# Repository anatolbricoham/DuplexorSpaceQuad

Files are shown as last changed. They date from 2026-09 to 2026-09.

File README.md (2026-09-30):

# Diplexor 2 m / 70 cm: PCB y caja imprimible (SMA y BNC)

Diplexor pasivo que separa las bandas de **2 m (144–146 MHz)** y **70 cm (430–440 MHz)** de un único conector de radio. Hay dos versiones que solo se diferencian en los conectores (**SMA** o **BNC**). Cada una tiene su PCB de 2 capas y su caja para impresora 3D, diseñada lo más compacta posible.

| | SMA | BNC |
|---|---|---|
| PCB | 37 × 23 mm | 55.5 × 33 mm |
| Caja (exterior) | **45.2 × 27.6 × 14.1 mm** | **59.9 × 37.6 × 23.5 mm** |
| Conector | Amphenol 132289 (canto, bulkhead) | Amphenol B6252HB-NPP3G-50 (acodado) |
| Tornillos | 2 × M2 × 10 autorroscantes | 2 × M2 × 12 autorroscantes |

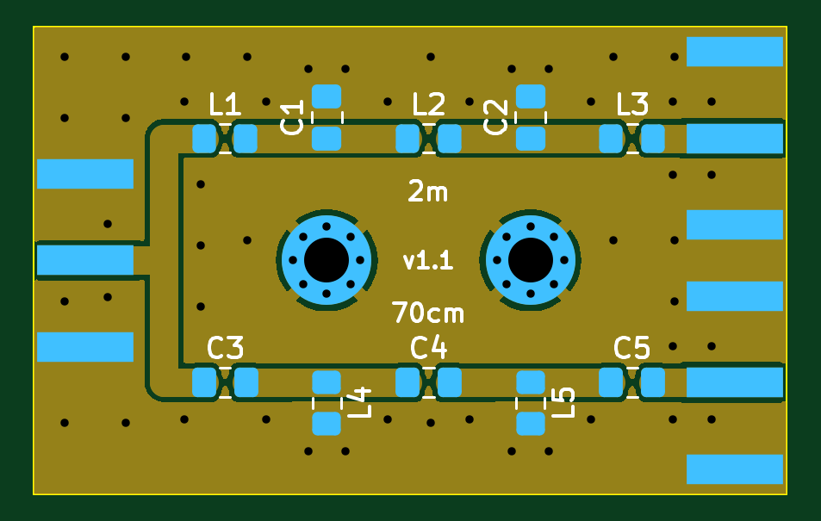
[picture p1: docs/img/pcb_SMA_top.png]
PCB SMA

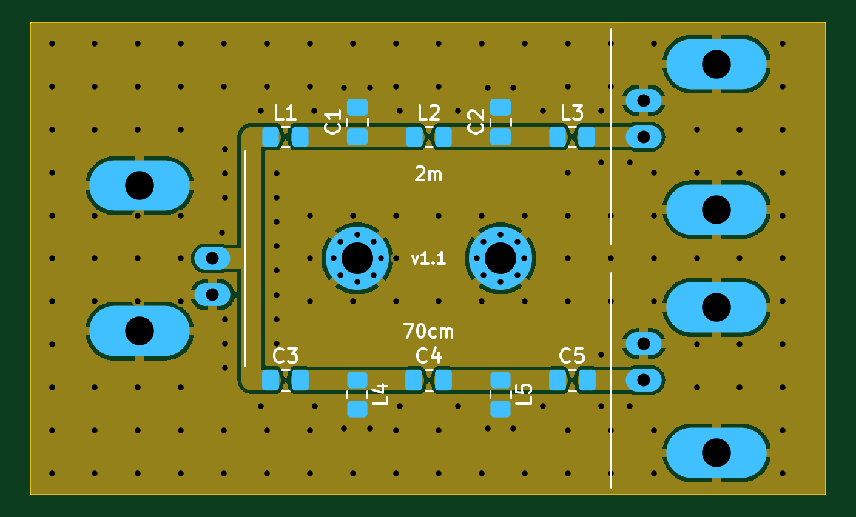
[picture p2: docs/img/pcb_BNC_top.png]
PCB BNC

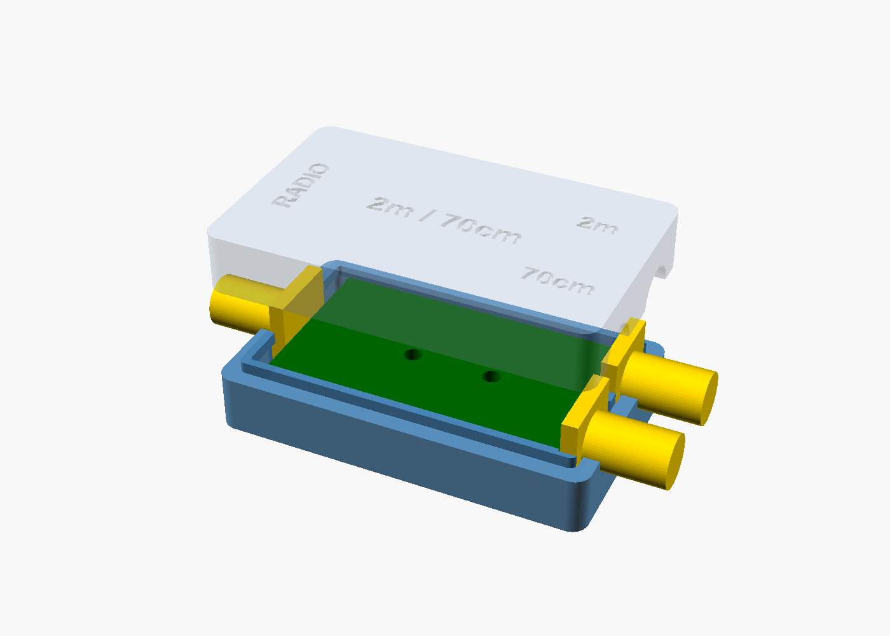
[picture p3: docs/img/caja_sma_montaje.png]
Caja SMA

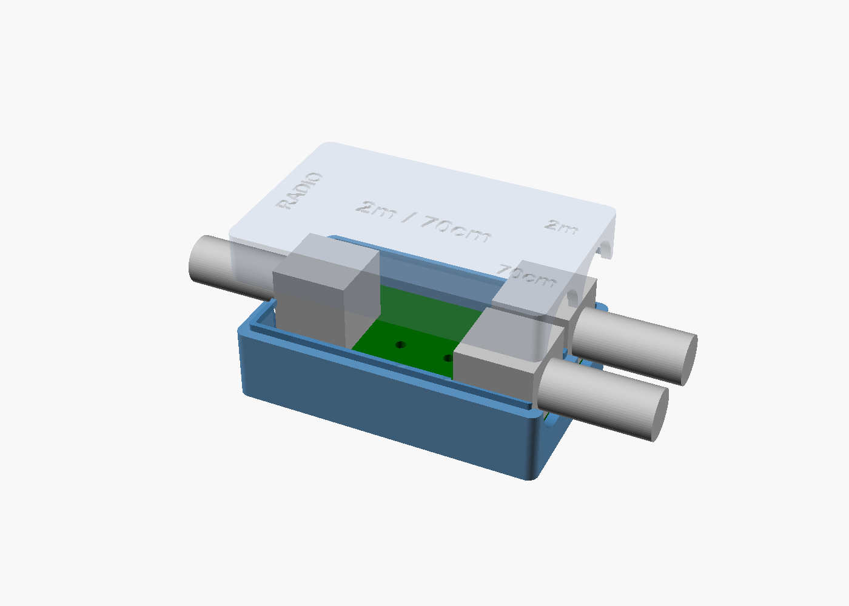
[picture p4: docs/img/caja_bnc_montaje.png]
Caja BNC


## Circuito

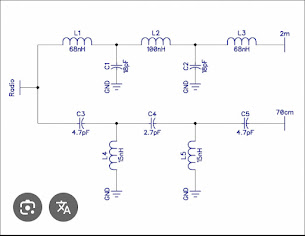
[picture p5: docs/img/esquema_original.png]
Esquema


- **2 m:** paso bajo formado por L1 68 nH, C1 18 pF, L2 100 nH, C2 18 pF y L3 68 nH.
- **70 cm:** paso alto formado por C3, L4 15 nH, C4, L5 15 nH y C5.

En el esquema original, el valor de C1/C2 es ambiguo (10 o 18 pF). Se ha usado **18 pF** porque con 10 pF la rama de 2 m queda desadaptada.

### Valores recomendados
Con los valores del esquema (C3 = C5 = 4.7 pF, C4 = 2.7 pF), la rama de 70 cm queda mal adaptada (S11 ≈ −6.4 dB, ROE ≈ 2.8). Con **C3 = C5 = 8.2 pF y C4 = 4.7 pF** mejora mucho. Se usan las mismas huellas:

| Simulación (ideal) | Esquema | Optimizado |
|---|---|---|
| S11 a 145 MHz | −19 dB | −31 dB |
| S11 a 435 MHz | −7 dB | −31 dB |
| Pérdida de inserción | 0.05 / 0.9 dB | < 0.05 dB |
| Aislamiento entre 2m y 70cm | > 50 dB | > 49 dB |

Puedes reproducirla con `make sim`.

## Estructura del repositorio
```
hardware/{SMA,BNC}/        Proyecto KiCad 7 (.kicad_pcb/.kicad_pro) + board_geometry.json
fabrication/{SMA,BNC}/     Gerber, taladros, zip para el fabricante, BOM, pick&place, informe DRC
enclosure/diplexor_caja.scad   Caja paramétrica (OpenSCAD)
enclosure/stl/             STL listos para imprimir (base + tapa por versión)
BOM/                       Listas de materiales (fuente)
scripts/                   Generador de PCB, simulador y script de build
docs/                      Imágenes, pruebas y montaje
```

## Fabricar la PCB
Sube `fabrication/<VERSION>/gerber_diplexor_2m70cm_<VERSION>.zip` al fabricante con estos parámetros:
- 2 capas, FR4 de **1.6 mm**, cobre de 1 oz y acabado HASL o ENIG.
- Pista y separación mínimas: 0.25 / 0.2 mm. Vía: 0.4 / 0.8 mm.
- Las líneas de RF son CPWG de 50 Ω (pista de 1.4 mm con 0.25 mm de separación a masa). El grosor de 1.6 mm es necesario para mantener esa impedancia.

## Imprimir la caja
- **Material:** PETG (recomendado) o PLA. Capa de 0.2 mm, 3 perímetros, relleno del 20 % o más.
- **Orientación:** la base con el suelo sobre la cama. La tapa ya se exporta boca abajo, con el techo sobre la cama.
- No hacen falta soportes. Los semicírculos de los conectores quedan como pequeños puentes.
- Es una caja "almeja": se abre a la altura del eje de los conectores. Un labio de 1.4 mm centra la tapa sobre la base.

Más detalles en [docs/MONTAJE.md](docs/MONTAJE.md).

> **Importante:** las medidas de los conectores de la caja (brida del SMA, altura y frontal del BNC) son estimaciones a partir de la huella de KiCad. **Mide tu conector con un calibre** y ajusta los parámetros `SMA_*` / `BNC_*` al principio de `enclosure/diplexor_caja.scad` antes de imprimir la versión final. También conviene imprimir primero solo la base y comprobar el ajuste.

## Pruebas
Consulta el protocolo con NanoVNA en [docs/PRUEBAS.md](docs/PRUEBAS.md).

## Regenerar todo
Requisitos: KiCad 7 (`kicad-cli` y el módulo Python `pcbnew`), `gerbv`, `openscad`, `python3-numpy` y `xvfb` (para los renders).
```bash
make          # PCB + DRC + Gerber + BOM/pos + imágenes + STL
make sim      # simulación del filtro
```
Todo sale de `scripts/gen_pcb.py`. La caja lee la posición de los conectores y de los agujeros desde `hardware/*/board_geometry.json`, así que si se mueve un conector en la PCB, la caja se adapta sola.

## Limitaciones
- Con componentes 0805 admite unos **5–10 W**, suficiente para equipos portátiles o QRP. Para más potencia hay que usar bobinas al aire y condensadores de mica o ATC.
- La caja de plástico no apantalla. La PCB lleva planos de masa en las dos caras con vías de cosido. Si hace falta blindaje, se puede pintar el interior con pintura conductora o forrarlo con cinta de cobre.

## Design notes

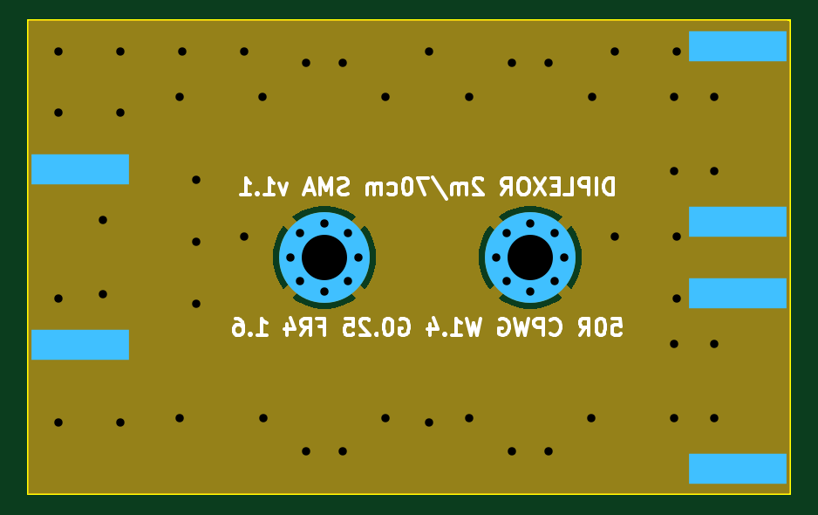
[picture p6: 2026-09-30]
docs/img/pcb_SMA_bottom.png

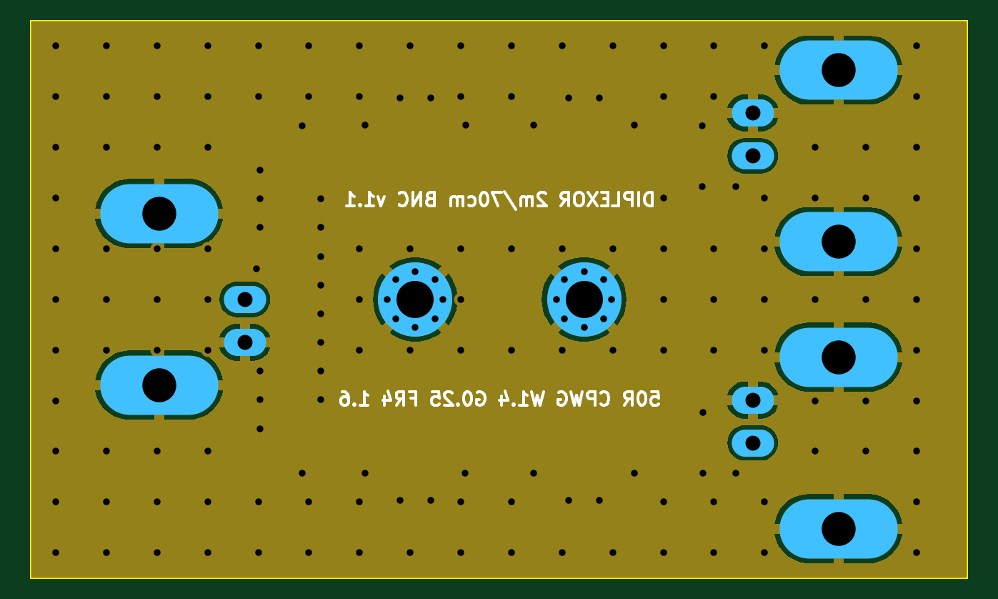
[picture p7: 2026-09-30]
docs/img/pcb_BNC_bottom.png

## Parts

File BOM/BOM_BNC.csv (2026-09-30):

Ref | Cant | Valor (esquema) | Valor optimizado (recomendado) | Encapsulado | Tipo recomendado
L1 L3 | 2 | 68nH | 68nH | 0805 | Inductor cerámico alta Q (p.ej. Coilcraft 0805CS-680XJL)
L2 | 1 | 100nH | 100nH | 0805 | Inductor cerámico alta Q (p.ej. Coilcraft 0805CS-101XJL)
L4 L5 | 2 | 15nH | 15nH | 0805 | Inductor cerámico alta Q (p.ej. Coilcraft 0805CS-150XJL)
C1 C2 | 2 | 18pF | 18pF | 0805 | C0G/NP0 >=100V alta Q
C3 C5 | 2 | 4.7pF | 8.2pF | 0805 | C0G/NP0 >=100V alta Q
C4 | 1 | 2.7pF | 4.7pF | 0805 | C0G/NP0 >=100V alta Q
J1 J2 J3 | 3 | BNC |  |  | Amphenol B6252HB-NPP3G-50 (BNC hembra; ángulo recto; PCB)
H1 H2 | 2 | M2 |  |  | Taladro 2.2 mm metalizado a masa
CAJA | 1 |  |  |  | Caja impresa 3D (enclosure/stl/caja_bnc_base.stl + _tapa.stl)
TORNILLO | 2 |  |  |  | M2 cabeza cilíndrica/alomada autorroscante: M2x12

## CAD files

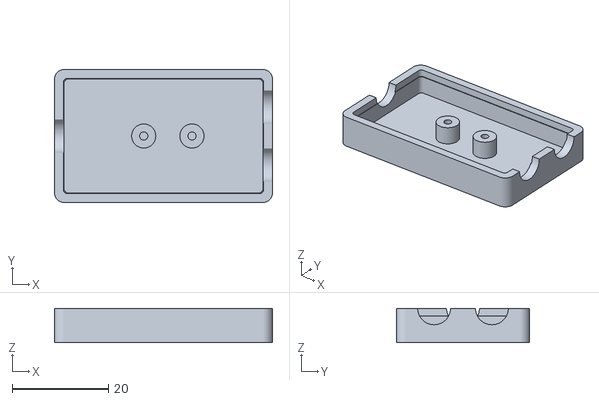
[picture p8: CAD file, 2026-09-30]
enclosure/stl/caja_sma_tapa.stl
45.2 x 27.6 x 7.10

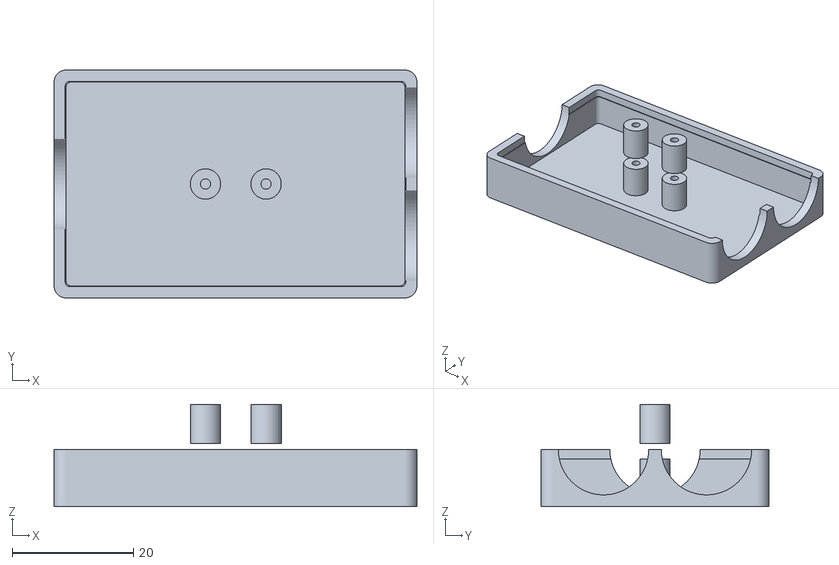
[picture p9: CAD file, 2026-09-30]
enclosure/stl/caja_bnc_tapa.stl
59.9 x 37.6 x 16.9

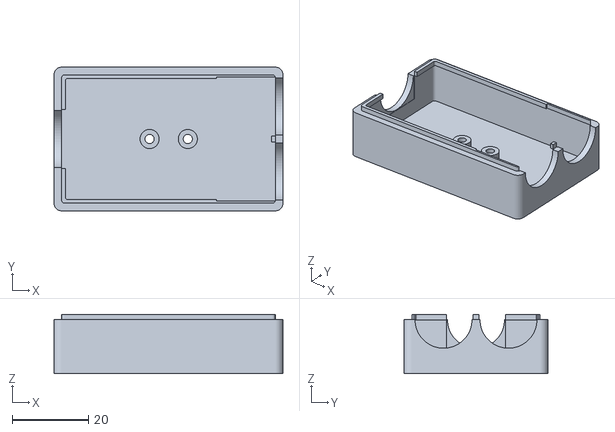
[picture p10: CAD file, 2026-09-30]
enclosure/stl/caja_bnc_base.stl
59.9 x 37.6 x 15.5

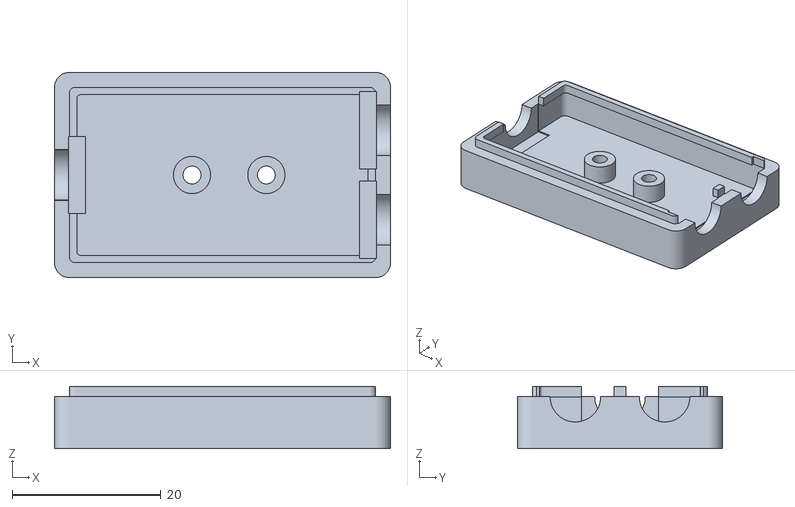
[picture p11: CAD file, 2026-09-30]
enclosure/stl/caja_sma_base.stl
45.2 x 27.6 x 8.40

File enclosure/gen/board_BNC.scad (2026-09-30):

// GENERADO por scripts/gen_enclosure_inc.py - no editar a mano
BNC_BOARD = [55.5, 33.0];
BNC_HOLES = [[22.800, 16.500], [32.800, 16.500]];
BNC_CONN  = [["J1", 12.700, 16.500, "left", "RADIO"], ["J2", 42.800, 8.000, "right", "2m"], ["J3", 42.800, 25.000, "right", "70cm"]];   // [ref, x, y(KiCad), lado, etiqueta]

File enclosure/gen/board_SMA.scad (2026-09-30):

// GENERADO por scripts/gen_enclosure_inc.py - no editar a mano
SMA_BOARD = [37.0, 23.0];
SMA_HOLES = [[14.400, 11.500], [24.400, 11.500]];
SMA_CONN  = [["J1", 2.540, 11.500, "left", "RADIO"], ["J2", 34.460, 5.500, "right", "2m"], ["J3", 34.460, 17.500, "right", "70cm"]];   // [ref, x, y(KiCad), lado, etiqueta]

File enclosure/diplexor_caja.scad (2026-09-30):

// =====================================================================
//  Caja imprimible 3D para el diplexor 2m/70cm (versiones SMA y BNC)
//  Diseño tipo "almeja": se parte a la altura del eje de los conectores,
//  así la PCB con los conectores soldados entra desde arriba.
//
//  Uso:
//    openscad -D 'VARIANT="SMA"' -D 'PART="base"' -o base.stl diplexor_caja.scad
//    VARIANT = "SMA" | "BNC"
//    PART    = "base" | "tapa" | "montaje"
//
//  Unidades: mm. Origen = esquina inferior-izquierda de la PCB, z = 0 en
//  la cara inferior de la PCB. La geometría de la PCB viene de
//  gen/board_<VARIANT>.scad (generado desde hardware/*/board_geometry.json).
// =====================================================================
VARIANT = "SMA";
PART    = "montaje";

include <gen/board_SMA.scad>   // define SMA_BOARD, SMA_HOLES, SMA_CONN
include <gen/board_BNC.scad>   // define BNC_BOARD, BNC_HOLES, BNC_CONN

$fn = 64;

// ---------------- parámetros generales ----------------
WALL   = 2.0;     // pared lateral
FLOOR  = 2.0;     // suelo (lleva el avellanado del tornillo)
ROOF   = 1.6;     // techo
CLR    = 0.3;     // holgura PCB-pared
FIT    = 0.15;    // holgura del labio de encaje
LIP_H  = 1.4;     // altura del labio base->tapa
LIP_T  = 1.0;     // grosor del labio
PCB_T  = 1.6;
POST_D = 5.0;     // columnas (base y tapa) sobre los agujeros M2
SCREW_CLR   = 2.4;   // paso M2
SCREW_PILOT = 1.7;   // rosca autorroscante M2 en PLA/PETG
HEAD_D = 4.4;  HEAD_H = 1.5;   // alojamiento cabeza M2 (DIN 7985 / ISO 7045)
TXT_DEPTH = 0.6;

// ---------------- parámetros por conector ----------------
// ¡Medir con calibre el conector real y ajustar si hace falta!
// SMA: Amphenol 132289 (end-launch bulkhead, rosca 1/4"-36)
SMA_AXIS   = PCB_T + 0.4;  // eje sobre la cara inferior de la PCB
SMA_FL_W   = 9.6;          // ancho/alto de la brida (cuadrada)
SMA_FL_T   = 1.9;          // espesor de la brida (queda dentro de la caja)
SMA_HOLE   = 6.8;          // taladro para la rosca 1/4"-36 (6.35 mm)
SMA_BELOW  = 3.0;          // espacio bajo la PCB (brida baja 2.8 mm)
SMA_ABOVE  = 4.8 + 0.4 + 0.3; // espacio sobre el eje (media brida + holgura)
// BNC: Amphenol B6252HB-NPP3G-50 (ángulo recto para PCB)
BNC_BODY_H = 14.8;         // altura del cuerpo sobre la PCB
BNC_AXIS   = PCB_T + 7.5;  // eje sobre la cara inferior de la PCB
BNC_HOLE   = 14.9;         // paso del frontal (casquillo + hexágono 12.7 e/c)
BNC_BELOW  = 3.0;          // patillas THT recortadas bajo la PCB
BNC_GAP    = 0.2;          // frontal del cuerpo -> pared interior

// ---------------- derivados ----------------
IS_SMA = VARIANT == "SMA";
BOARD  = IS_SMA ? SMA_BOARD : BNC_BOARD;
HOLES  = IS_SMA ? SMA_HOLES : BNC_HOLES;
CONN   = IS_SMA ? SMA_CONN  : BNC_CONN;
BW = BOARD[0]; BH = BOARD[1];
AXIS  = IS_SMA ? SMA_AXIS : BNC_AXIS;
HOLE  = IS_SMA ? SMA_HOLE : BNC_HOLE;
GAPX  = IS_SMA ? SMA_FL_T + 0.2 : BNC_GAP;       // hueco en las caras con conector
Z_IN_BOT = -(IS_SMA ? SMA_BELOW : BNC_BELOW);
Z_IN_TOP = IS_SMA ? AXIS + SMA_ABOVE : PCB_T + BNC_BODY_H + 0.5;
X0 = -GAPX;          X1 = BW + GAPX;       // interior
Y0 = -CLR;           Y1 = BH + CLR;
Z_SPLIT = AXIS;
OUT = [X1 - X0 + 2*WALL, Y1 - Y0 + 2*WALL];

function ky(y) = BH - y;       // KiCad (y hacia abajo) -> OpenSCAD

module rbox(p0, p1, r=1.2) {   // caja con aristas verticales redondeadas
    hull() for (x=[p0[0]+r, p1[0]-r], y=[p0[1]+r, p1[1]-r])
        translate([x, y, p0[2]]) cylinder(r=r, h=p1[2]-p0[2]);
}

module outer_shell(z0, z1) rbox([X0-WALL, Y0-WALL, z0], [X1+WALL, Y1+WALL, z1], 2.0);
module inner_space(z0, z1) rbox([X0, Y0, z0], [X1, Y1, z1], 0.8);

module conn_cuts() {
    for (c = CONN) {
        sx = c[3] == "left" ? X0 - WALL - 1 : X1 - 1;
        translate([sx, ky(c[2]), AXIS]) rotate([0, 90, 0])
            cylinder(d=HOLE, h=WALL + 2 + 1);
    }
}

module labels() {
    zt = Z_IN_TOP + ROOF;
    for (c = CONN) {
        left = c[3] == "left";
        tx = left ? X0 + 2.8 : X1 - 5;
        translate([tx, ky(c[2]), zt - TXT_DEPTH])
            linear_extrude(TXT_DEPTH + 0.1)
                rotate(left ? 90 : 0)
                text(c[4], size = IS_SMA ? 2.4 : 3.2, halign="center", valign="center",
                     font="Liberation Sans:style=Bold");
    }
    translate([(X0 + X1)/2, (Y0 + Y1)/2, zt - TXT_DEPTH])
        linear_extrude(TXT_DEPTH + 0.1)
            text("2m / 70cm", size = IS_SMA ? 2.8 : 4.0, halign="center", valign="center",
                 font="Liberation Sans:style=Bold");
}

module base() {
    difference() {
        union() {
            difference() {
                outer_shell(Z_IN_BOT - FLOOR, Z_SPLIT);
                inner_space(Z_IN_BOT, Z_SPLIT + 1);
            }
            // labio de centrado
            difference() {
                rbox([X0, Y0, Z_SPLIT - 0.01], [X1, Y1, Z_SPLIT + LIP_H], 0.8);
                rbox([X0 + LIP_T, Y0 + LIP_T, Z_SPLIT - 1], [X1 - LIP_T, Y1 - LIP_T, Z_SPLIT + LIP_H + 1], 0.5);
            }
            // columnas de apoyo de la PCB
            for (h = HOLES) translate([h[0], ky(h[1]), Z_IN_BOT - 0.01])
                cylinder(d=POST_D, h=-Z_IN_BOT + 0.01);
        }
        conn_cuts();
        conn_envelope();
        for (h = HOLES) translate([h[0], ky(h[1]), 0]) {
            translate([0, 0, Z_IN_BOT - FLOOR - 1]) cylinder(d=SCREW_CLR, h=50);
            translate([0, 0, Z_IN_BOT - FLOOR - 0.01]) cylinder(d=HEAD_D, h=HEAD_H);
        }
    }
}

module lid() {
    difference() {
        union() {
            difference() {
                outer_shell(Z_SPLIT, Z_IN_TOP + ROOF);
                inner_space(Z_SPLIT - 1, Z_IN_TOP);
            }
            // columnas que pisan la PCB
            for (h = HOLES) translate([h[0], ky(h[1]), PCB_T])
                cylinder(d=POST_D, h=Z_IN_TOP - PCB_T + 0.01);
        }
        // hueco para el labio de la base
        rbox([X0 - FIT, Y0 - FIT, Z_SPLIT - 1], [X1 + FIT, Y1 + FIT, Z_SPLIT + LIP_H + FIT], 0.8);
        conn_cuts();
        for (h = HOLES) translate([h[0], ky(h[1]), PCB_T - 0.01])
            cylinder(d=SCREW_PILOT, h=Z_IN_TOP - PCB_T - 0.6);
        labels();
    }
}

// volumen ocupado por cada conector dentro de la caja (se resta del labio)
module conn_envelope() {
    for (c = CONN) {
        left = c[3] == "left";
        if (IS_SMA) {
            e = SMA_FL_W/2 + 0.4;
            translate([left ? X0 - 0.1 : BW - 0.1, ky(c[2]) - e, AXIS - e])
                cube([GAPX + 0.2, 2*e, 2*e]);
        } else {
            translate([left ? X0 - 0.1 : BW - 14.9 - 0.3, ky(c[2]) - 7.35 - 0.4, PCB_T - 0.1])
                cube([14.9 + 0.3 + 0.2 + 0.1, 14.7 + 0.8, BNC_BODY_H + 0.6]);
        }
    }
}

// ---------- maquetas (solo para la vista de montaje) ----------
module pcb_mock() {
    color("darkgreen") difference() {
        cube([BW, BH, PCB_T]);
        for (h = HOLES) translate([h[0], ky(h[1]), -1]) cylinder(d=2.2, h=5);
    }
    for (c = CONN) {
        dir = c[3] == "left" ? -1 : 1;
        ex  = c[3] == "left" ? 0 : BW;
        if (IS_SMA) color("gold") translate([ex, ky(c[2]), AXIS]) {
            translate([dir > 0 ? 0 : -SMA_FL_T, -SMA_FL_W/2, -SMA_FL_W/2]) cube([SMA_FL_T, SMA_FL_W, SMA_FL_W]);
            rotate([0, 90*dir, 0]) cylinder(d=6.35, h=SMA_FL_T + 9.5);
        } else color("silver") translate([ex, ky(c[2]), PCB_T]) {
            translate([dir > 0 ? -14.9 : 0, -7.35, 0]) cube([14.9, 14.7, BNC_BODY_H]);
            translate([0, 0, AXIS - PCB_T]) rotate([0, 90*dir, 0]) cylinder(d=9.6, h=20.6);
        }
    }
}

if (PART == "base") base();
else if (PART == "tapa") translate([0, 0, Z_IN_TOP + ROOF]) rotate([180, 0, 0]) lid(); // boca abajo para imprimir
else if (PART == "check_base") intersection() { base(); translate([0,0,0.02]) pcb_mock(); }
else if (PART == "check_tapa") intersection() { lid(); translate([0,0,0.02]) pcb_mock(); }
else {
    color("SteelBlue", 0.9) base();
    pcb_mock();
    color("LightSteelBlue", 0.35) translate([0, 0, 12]) lid();   // tapa "explotada"
}

echo(str("CAJA ", VARIANT, ": exterior ", OUT[0], " x ", OUT[1], " x ",
         Z_IN_TOP + ROOF - (Z_IN_BOT - FLOOR), " mm"));

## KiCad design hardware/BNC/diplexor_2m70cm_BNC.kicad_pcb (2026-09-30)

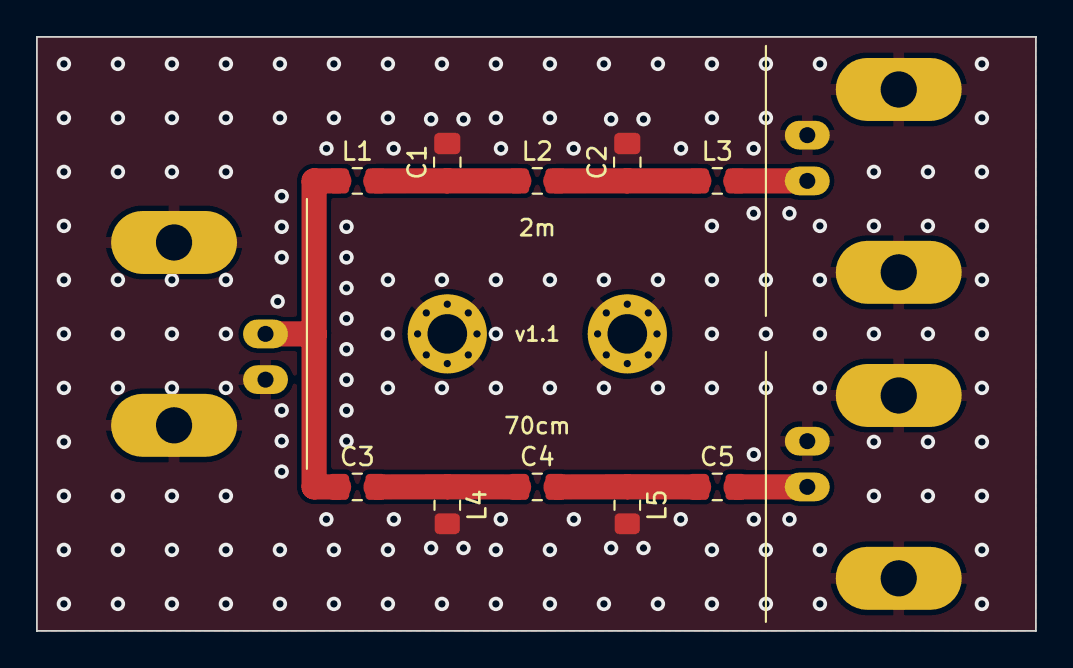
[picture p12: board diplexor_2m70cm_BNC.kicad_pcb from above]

Board: 2 copper layers, 55.5 x 33.0 mm, 15 parts (0 on the bottom side), 8 nets.

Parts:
C1, C2: 18pF; C_0805_2012Metric_Pad1.18x1.45mm_HandSolder
C3, C5: 4.7pF; C_0805_2012Metric_Pad1.18x1.45mm_HandSolder
C4: 2.7pF; C_0805_2012Metric_Pad1.18x1.45mm_HandSolder
H1, H2: M2; MountingHole_2.2mm_M2_Pad_Via
J1, J2, J3: BNC R/A PCB (Amphenol B6252HB-NPP3G-50); BNC_Amphenol_B6252HB-NPP3G-50_Horizontal
L1, L3: 68nH; L_0805_2012Metric_Pad1.15x1.40mm_HandSolder
L2: 100nH; L_0805_2012Metric_Pad1.15x1.40mm_HandSolder
L4, L5: 15nH; L_0805_2012Metric_Pad1.15x1.40mm_HandSolder

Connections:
GND: C1.2, C2.2, H1.1, H2.1, J1.2, J2.2, J3.2, L4.2, L5.2
N1: C1.1, L1.2, L2.1
N2: C2.1, L2.2, L3.1
N3: C3.2, C4.1, L4.1
N4: C4.2, C5.1, L5.1
OUT_2M: J2.1, L3.2
OUT_70CM: C5.2, J3.1
RADIO: C3.1, J1.1, L1.1

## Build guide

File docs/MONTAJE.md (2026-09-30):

# Montaje

1. **Soldar el SMD** (0805): primero las bobinas y los condensadores en serie, después los que van a masa (C1, C2, L4 y L5).
   Los pads a masa están unidos al plano sin alivio térmico, así que necesitan más calor (punta ancha, unos 350 °C).
2. **Soldar los conectores:**
   - **SMA:** mete el canto de la PCB entre las patas del conector hasta que la brida toque el borde.
     Suelda el pin central al pad y las 4 patas de masa, por arriba y por abajo.
   - **BNC:** inserta el conector y suelda el pin central, el pin de masa y las dos patas de anclaje.
     Corta las patillas a 2.5 mm como máximo por debajo de la PCB.
3. **Probar** antes de cerrar la caja (ver [PRUEBAS.md](PRUEBAS.md)).
4. **Cerrar la caja:**
   1. Apoya la PCB sobre las dos columnas de la base. Los conectores quedan en los semicírculos de las paredes.
   2. Coloca la tapa encima. El labio la centra.
   3. Atornilla desde abajo con 2 tornillos M2 autorroscantes (SMA: M2×10, BNC: M2×12).
      Los tornillos atraviesan la base y la PCB y roscan en las columnas de la tapa.
   4. **SMA:** si quieres, pon la tuerca de panel de 1/4"-36 por fuera para reforzar la pared.
      No la aprietes en exceso.

## Parámetros de la caja (enclosure/diplexor_caja.scad)
| Parámetro | Valor por defecto | Qué es |
|---|---|---|
| `SMA_FL_W` / `SMA_FL_T` | 9.6 / 1.9 mm | Ancho y grosor de la brida del SMA |
| `SMA_AXIS` | PCB + 0.4 mm | Altura del eje del SMA |
| `SMA_HOLE` | 6.8 mm | Paso de la rosca de 1/4"-36 |
| `BNC_BODY_H` | 14.8 mm | Altura del cuerpo del BNC sobre la PCB |
| `BNC_AXIS` | PCB + 7.5 mm | Altura del eje del BNC |
| `BNC_HOLE` | 14.9 mm | Paso del frontal del BNC |
| `WALL` / `FLOOR` / `ROOF` | 2.0 / 2.0 / 1.6 mm | Grosor de las paredes |
| `FIT` | 0.15 mm | Holgura del labio de encaje (auméntala si la tapa entra justa) |

Para regenerar los STL después de cambiar parámetros, ejecuta `make` o:
`openscad -D 'VARIANT="SMA"' -D 'PART="base"' -o caja_sma_base.stl enclosure/diplexor_caja.scad`

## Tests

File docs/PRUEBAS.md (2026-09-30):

# Protocolo de pruebas (NanoVNA o analizador vectorial)

| # | Prueba | Montaje | Criterio de aceptación |
|---|---|---|---|
| 1 | Cortos y continuidad | Polímetro | RADIO–masa: ni corto ni resistencia baja en DC (la rama de 70 cm tiene condensadores en serie). RADIO–2m: continuidad en DC. |
| 2 | Adaptación (S11) | VNA en RADIO; carga de 50 Ω en 2m y en 70cm | < −15 dB entre 144 y 146 MHz y entre 430 y 440 MHz |
| 3 | Rama 2 m (S21) | RADIO → 2m; carga de 50 Ω en 70cm | Pérdida < 0.5 dB a 145 MHz; rechazo > 35 dB a 435 MHz |
| 4 | Rama 70 cm (S21) | RADIO → 70cm; carga de 50 Ω en 2m | Pérdida < 0.7 dB a 435 MHz; rechazo > 35 dB a 145 MHz |
| 5 | Aislamiento | 2m → 70cm; carga de 50 Ω en RADIO | > 35 dB en las dos bandas |
| 6 | Potencia | Radio → diplexor → vatímetro/ROE → carga | Subir 1 → 5 → 10 W: ROE estable y sin calentamiento apreciable |

Recomendaciones:
- Calibra el VNA (SOL + Thru) en el extremo de los cables que vayas a usar.
- Barrido recomendado: de 100 a 500 MHz con 401 puntos o más.
- Si la banda de 70 cm aparece desplazada por los parásitos de la PCB:
  - Si queda baja, reduce C4 un escalón (4.7 → 3.9 pF).
  - Si queda alta, sube L4 y L5 (15 → 18 nH).
- Resultados de la simulación ideal: `make sim`.

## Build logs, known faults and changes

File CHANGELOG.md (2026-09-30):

# Cambios

## v1.1 (2026-09-30)
- PCB compactas: SMA 37 × 23 mm (antes 50 × 40) y BNC 55.5 × 33 mm (antes 70 × 56).
- Los agujeros M3 de las esquinas pasan a 2 agujeros M2 centrales, que fijan la PCB a la caja.
- Caja imprimible en 3D para cada versión, paramétrica (OpenSCAD) y generada a partir de la geometría de la PCB.
- Script de simulación y compilación reproducible (`make`).

## v1.0
- Primera versión: PCB SMA 50 × 40 mm y PCB BNC 70 × 56 mm, con agujeros M3.
